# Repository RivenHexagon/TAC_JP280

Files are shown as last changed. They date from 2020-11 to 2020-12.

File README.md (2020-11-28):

# Total Audio Concepts (TAC) Scorpion Mixing Console Overhaul
## PCB JP280

Redesign of Monitor Connector Card (PCB JP280) in order to populate it with gold
plated Audio Jacks and Molex connectors. The original PCB exceeds the dimensions
of an Eurocard (100 mm x 160 mm) substrate. Luckily it's possible to split it up
into two independet parts, so the layouts can be placed on a copper-plated blank
and etched in a DIY process (see mirrored image of original PCB).

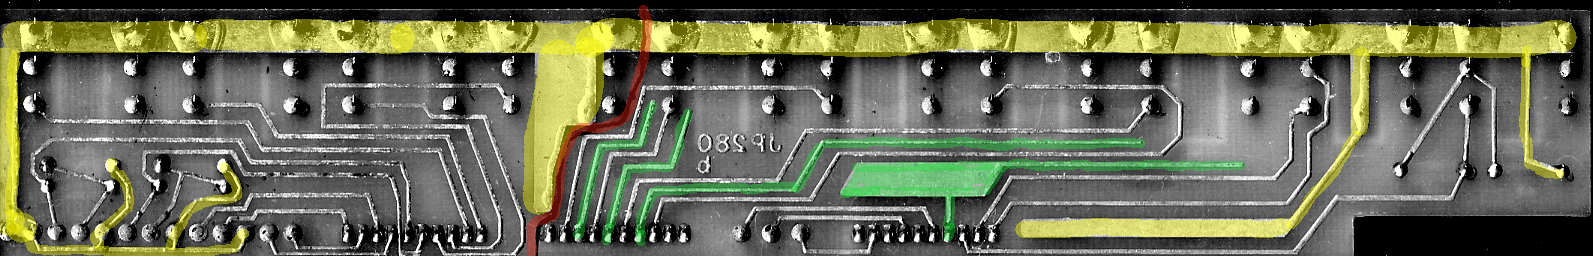
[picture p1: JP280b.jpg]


## Made With

I named the new versions JP280C1 & JP280C2 and made them with KiCad 5.1.7. using
a git submodule that handles any special footprints:

https://github.com/RivenHexagon/TAC_KiCad_lib.git

## Further Modifications

The XLR/audio jacks SK1 - SK4 are mounted to the back panel and were then solder
wired to the PCB. The solder connections have now been replaced with 3-pin Molex
connectors.

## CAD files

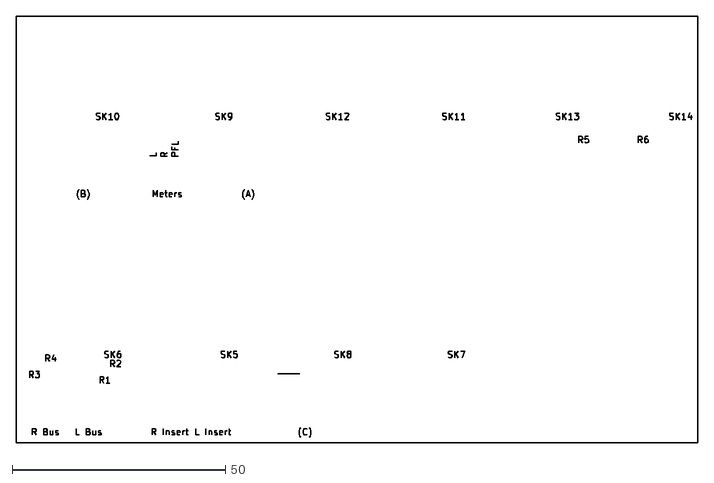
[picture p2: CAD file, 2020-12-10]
JP280C-Cmts_User.dxf
160.0 x 100.0

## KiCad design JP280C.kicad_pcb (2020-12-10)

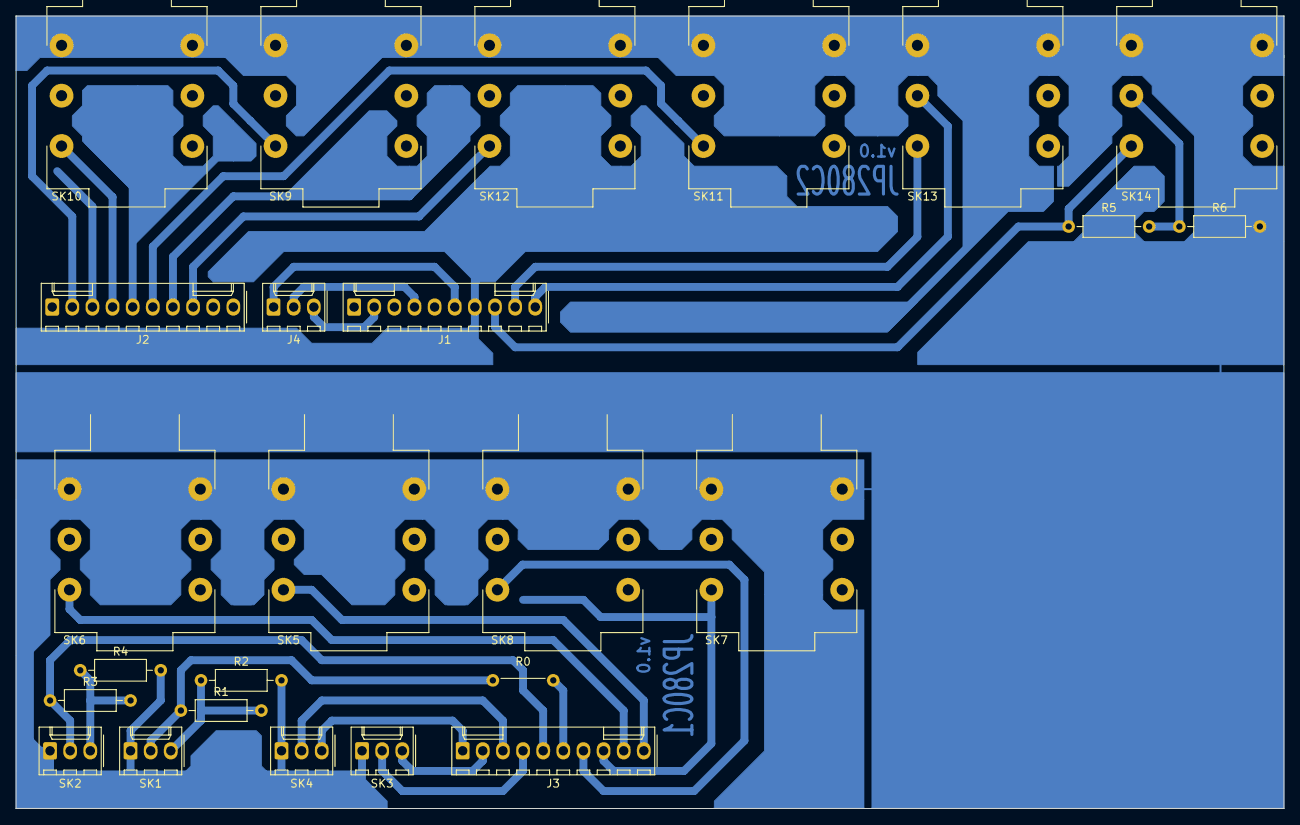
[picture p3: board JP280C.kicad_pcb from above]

Board: 2 copper layers, 160.0 x 100.0 mm, 25 parts (0 on the bottom side), 25 nets.

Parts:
J1: Ribbon Cable (A); Molex_KK-254_AE-6410-10A_1x10_P2.54mm_Vertical_reversed
J2: Ribbon Cable (B); Molex_KK-254_AE-6410-10A_1x10_P2.54mm_Vertical_reversed
J3: Ribbon Cable (C); Molex_KK-254_AE-6410-10A_1x10_P2.54mm_Vertical_reversed
J4: Meters; Molex_KK-254_AE-6410-03A_1x03_P2.54mm_Vertical_reversed
R0: 0R; Wire_Bridge_P7.62mm_Horizontal
R1, R3: 3k; R_Axial_DIN0207_L6.3mm_D2.5mm_P10.16mm_Horizontal
R2, R4: 1k; R_Axial_DIN0207_L6.3mm_D2.5mm_P10.16mm_Horizontal
R5: 10k; R_Axial_DIN0207_L6.3mm_D2.5mm_P10.16mm_Horizontal
R6: 10R; R_Axial_DIN0207_L6.3mm_D2.5mm_P10.16mm_Horizontal
SK1: Left Bus; Molex_KK-254_AE-6410-03A_1x03_P2.54mm_Vertical_reversed
SK2: Right Bus; Molex_KK-254_AE-6410-03A_1x03_P2.54mm_Vertical_reversed
SK3: Left Insert; Molex_KK-254_AE-6410-03A_1x03_P2.54mm_Vertical_reversed
SK4: Right Insert; Molex_KK-254_AE-6410-03A_1x03_P2.54mm_Vertical_reversed
SK5: Left Monitor; CL13345
SK6: Right Monitor; CL13345
SK7: Left Aux Monitor; CL13345
SK8: Right Aux Monitor; CL13345
SK9: Left Tape 2; CL13345
SK10: Right Tape 2; CL13345
SK11: Left Tape 1; CL13345
SK12: Right Tape 1; CL13345
SK13: Talkback; CL13345
SK14: OSC; CL13345

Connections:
GND: R2.2, R4.2, R6.2, SK1.1, SK2.1, SK3.1, SK4.1, SK5.S, SK5.SN, SK6.S, SK6.SN, SK7.S, SK7.SN, SK8.S, SK8.SN, SK9.S, SK9.SN, SK10.S, SK10.SN, SK11.S, SK11.SN, SK12.S, SK12.SN, SK13.S, SK13.SN, SK14.S, SK14.SN
unnamed: J1.2, J4.3
unnamed: J1.4, J4.2
unnamed: J1.6, J4.1
unnamed: J1.8, R5.1, SK14.T
unnamed: J1.9, SK13.T
unnamed: J1.10, SK13.R
unnamed: J2.2, SK9.T
unnamed: J2.4, SK10.T
unnamed: J2.6, SK11.T
unnamed: J2.8, SK12.T
unnamed: J3.1, SK4.3
unnamed: J3.2, SK3.3
unnamed: J3.3, SK4.2
unnamed: J3.4, SK3.2
unnamed: J3.5, R3.1, SK2.2
unnamed: J3.6, R0.2
unnamed: J3.7, SK8.T
unnamed: J3.8, SK7.T
unnamed: J3.9, SK6.T
unnamed: J3.10, SK5.T
unnamed: R0.1, R1.1, SK1.2
unnamed: R1.2, R2.1, SK1.3
unnamed: R3.2, R4.1, SK2.3
unnamed: R5.2, R6.1, SK14.R

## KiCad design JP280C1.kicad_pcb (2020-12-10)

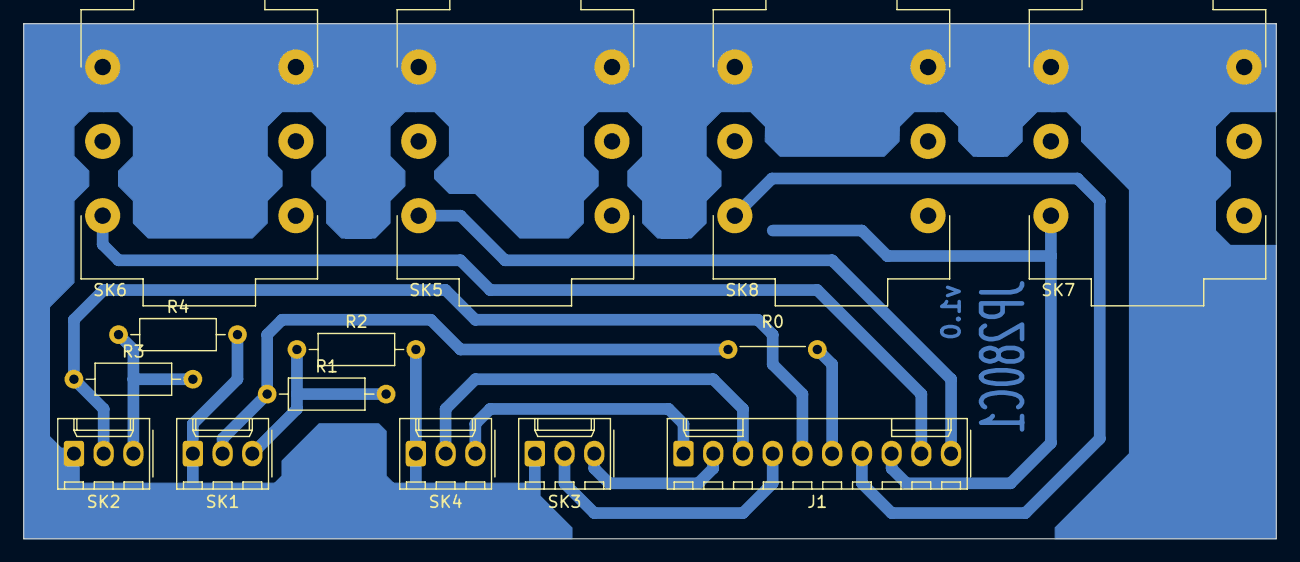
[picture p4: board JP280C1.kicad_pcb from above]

Board: 2 copper layers, 107.0 x 44.0 mm, 14 parts (0 on the bottom side), 14 nets.

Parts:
J1: Ribbon Cable (C); Molex_KK-254_AE-6410-10A_1x10_P2.54mm_Vertical_reversed
R0: 0R; Wire_Bridge_P7.62mm_Horizontal
R1, R3: 3k; R_Axial_DIN0207_L6.3mm_D2.5mm_P10.16mm_Horizontal
R2, R4: 1k; R_Axial_DIN0207_L6.3mm_D2.5mm_P10.16mm_Horizontal
SK1: Left Bus; Molex_KK-254_AE-6410-03A_1x03_P2.54mm_Vertical_reversed
SK2: Right Bus; Molex_KK-254_AE-6410-03A_1x03_P2.54mm_Vertical_reversed
SK3: Left Insert; Molex_KK-254_AE-6410-03A_1x03_P2.54mm_Vertical_reversed
SK4: Right Insert; Molex_KK-254_AE-6410-03A_1x03_P2.54mm_Vertical_reversed
SK5: Left Monitor; CL13345
SK6: Right Monitor; CL13345
SK7: Left Aux Monitor; CL13345
SK8: Right Aux Monitor; CL13345

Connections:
GND: R2.2, R4.2, SK1.1, SK2.1, SK3.1, SK4.1, SK5.S, SK5.SN, SK6.S, SK6.SN, SK7.S, SK7.SN, SK8.S, SK8.SN
unnamed: J1.1, SK4.3
unnamed: J1.2, SK3.3
unnamed: J1.3, SK4.2
unnamed: J1.4, SK3.2
unnamed: J1.5, R3.1, SK2.2
unnamed: J1.6, R0.2
unnamed: J1.7, SK8.T
unnamed: J1.8, SK7.T
unnamed: J1.9, SK6.T
unnamed: J1.10, SK5.T
unnamed: R0.1, R1.1, SK1.2
unnamed: R1.2, R2.1, SK1.3
unnamed: R3.2, R4.1, SK2.3

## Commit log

2020-11-23 empty project for board 1/2 (110x44)
    [CL13345.step, JP280C1.kicad_pcb, JP280C1.sch]
2020-11-23 wiring done for board 1/2
    [JP280C1.sch]
2020-11-26 footprints assigned
    [JP280C1.sch]
2020-11-26 placed Audio Jacks horizontally on metirc grid
    [JP280C1.kicad_pcb]
2020-11-26 completed wiring
    [JP280C1.kicad_pcb]
2020-11-26 updated footprint 3d model and flipped copper
    [JP280C1.kicad_pcb]
2020-11-26 corrected placement of SK7 and SK8
    [JP280C1.kicad_pcb]
2020-11-27 preparing to add libs as submodule
    [CL13345.step, JP280C1.kicad_pcb]
2020-11-27 replaced vias with wire bridge
    [JP280C1.sch]
2020-11-27 added copper fill
    [JP280C1.kicad_pcb]
2020-11-29 schematic done for JP280C2
    [JP280C1.kicad_pcb, JP280C1.sch, JP280C2.kicad_pcb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]
2020-11-29 PBC wiring complete
    [JP280C2.kicad_pcb, JP280C2.sch]
2020-11-29 part of copper pour
    [JP280C2.kicad_pcb]
2020-11-29 completed copper pour
    [JP280C1.kicad_pcb, JP280C2.kicad_pcb]
2020-12-10 merged both PCBs into one project JP280C and arranged them on a 160 mm x 100 mm Eurocard substrate
    [JP280C.kicad_pcb, JP280C.sch]
2020-12-10 narrowed JP208C1 to 107 mm; added engravings to Cmts.User layer
    [JP280C-Cmts_User.dxf, JP280C.kicad_pcb, JP280C1.kicad_pcb]
